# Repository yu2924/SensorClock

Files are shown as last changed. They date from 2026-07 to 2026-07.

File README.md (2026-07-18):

# SensorClock

🚧UNDER CONSTRUCTION🚧

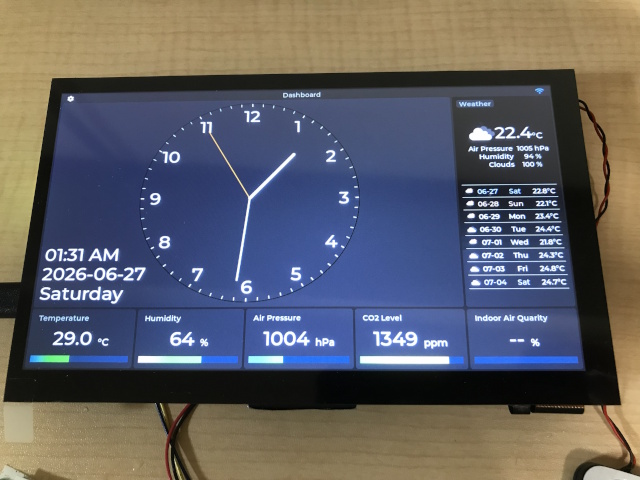
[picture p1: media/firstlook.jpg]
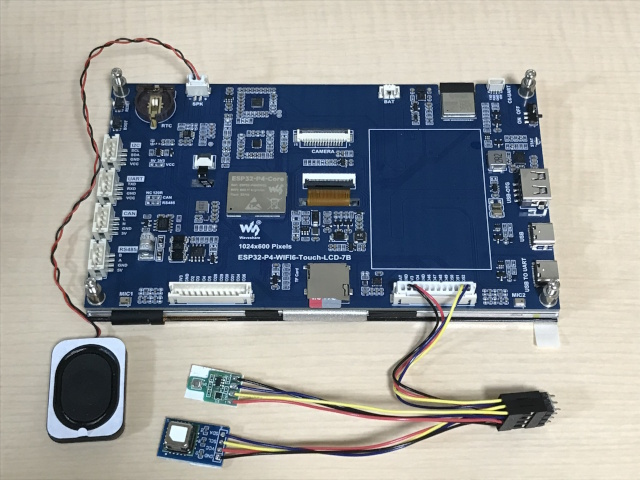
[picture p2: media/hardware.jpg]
 

> この家には壁掛け時計も置時計も無いな。一つ欲しいな。出来れば気温や湿度やCO2濃度なんかも見られたら良いな。

This is a documentation of my personal project to build a table clock with environmental sensors using a HMI display panel.

- It displays the current time and date, keeping the time synchronized using SNTP over Wi-Fi.
- It displays readings from environmental sensors, and optionally issues alerts when necessary.
- It displays a one-week weather forecast using [OpenWeather® One Call API 4.0](https://openweathermap.org/api/one-call-4). (API key required)
- It stores three months' worth of environmental data as a data logger and provides it in JSON format via an HTTP server.

**Table of Contents**

- [1. Hadrware](#1-hadrware)
	- [1.1. About Battery Operation](#11-about-battery-operation)
	- [1.2. 日本国内における技術基準適合証明](#12-日本国内における技術基準適合証明)
- [2. Tools Required for Development](#2-tools-required-for-development)
- [3. Firmware](#3-firmware)
	- [3.1. Introduction](#31-introduction)
	- [3.2. Configuration](#32-configuration)
	- [3.3. Preparing Fonts](#33-preparing-fonts)
	- [3.4. Options](#34-options)
		- [3.4.1. Choosing Screen Resolution](#341-choosing-screen-resolution)
		- [3.4.2. Enabling HTTPS Support for the HistoryServer](#342-enabling-https-support-for-the-historyserver)
	- [3.5. Security Consideration](#35-security-consideration)
	- [3.6. How The DataLogger and the HistoryServer Works](#36-how-the-datalogger-and-the-historyserver-works)
- [4. Developed by / License for the Created Data](#4-developed-by--license-for-the-created-data)
- [5. Acknowledgments](#5-acknowledgments)

## 1. Hadrware

- [WaveShare ESP32-P4-WIFI6-Touch-LCD-7B](https://docs.waveshare.com/ESP32-P4-WIFI6-Touch-LCD-7B) HMI display panel (7inch 1024 × 600)
- BME680 I2C temperature, humidity, barometric pressure, and gas sensor module
- SCD41 I2C CO2 sensor module



### 1.1. About Battery Operation

Since the steady-state current of the HMI panel is around 300 mA, battery power is not a practical option for a stationary device (IMO).

### 1.2. 日本国内における技術基準適合証明

この制作で使用したHMIディスプレイパネル製品は認証取得済みのモジュールを搭載しています。

- モジュール: ESP32-C6-MINI-1
- 認可番号: [007-AN0136](media/ESP32-C6-MINI-1%20TELEC%20Certification.pdf)

cf. [認証取得済みモジュールを内蔵する製品の場合](https://www.telec.or.jp/faq/#faq1_17)

---

## 2. Tools Required for Development

- [Visual Studio Code](https://code.visualstudio.com/)
- [ESP-IDF Extension for VS Code](https://marketplace.visualstudio.com/items?itemName=espressif.esp-idf-extension)
- [FontForge](https://fontforge.org/)
- [QCAD](https://www.qcad.org/)
- [OpenSCAD](https://openscad.org/)
- 3D printers
- solder and soldering irons
- wire strippers, wire cutters, pliers, files, screwdrivers, etc.

---

## 3. Firmware

### 3.1. Introduction

As I was getting started with firmware development, I learned that LVGL offers [a Win32 port](https://github.com/lvgl/lv_port_pc_visual_studio).  So, I decided to divide the application into modules, prototype most of the implementation to run on Windows, and replace only the platform-dependent modules with implementations using ESP-IDF/FreeRTOS functions.

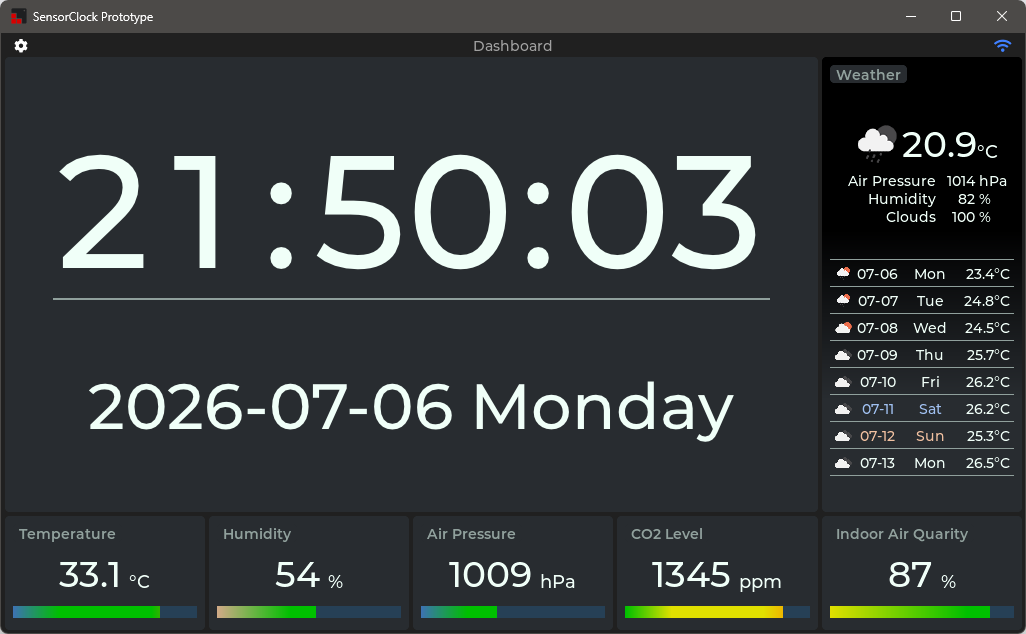
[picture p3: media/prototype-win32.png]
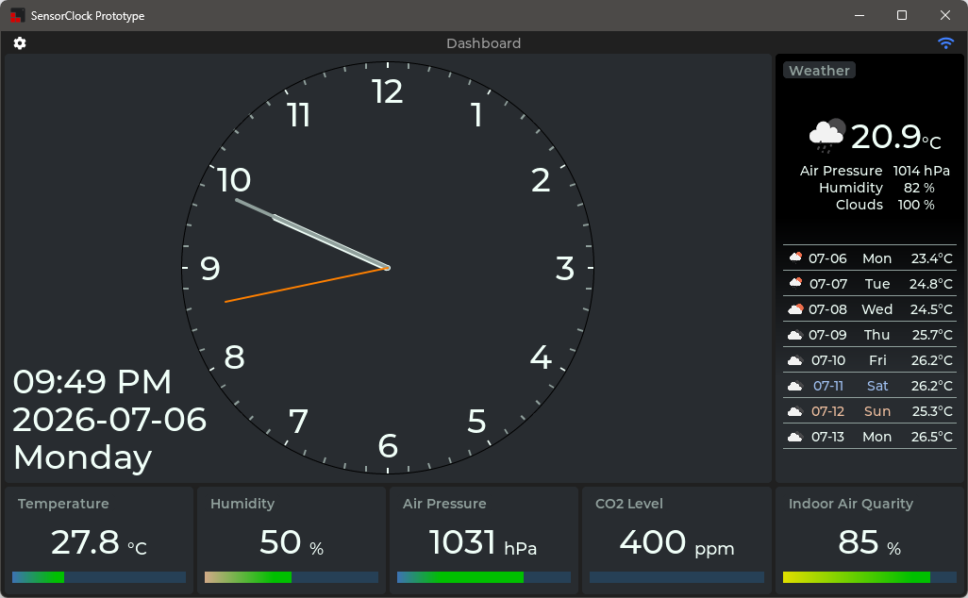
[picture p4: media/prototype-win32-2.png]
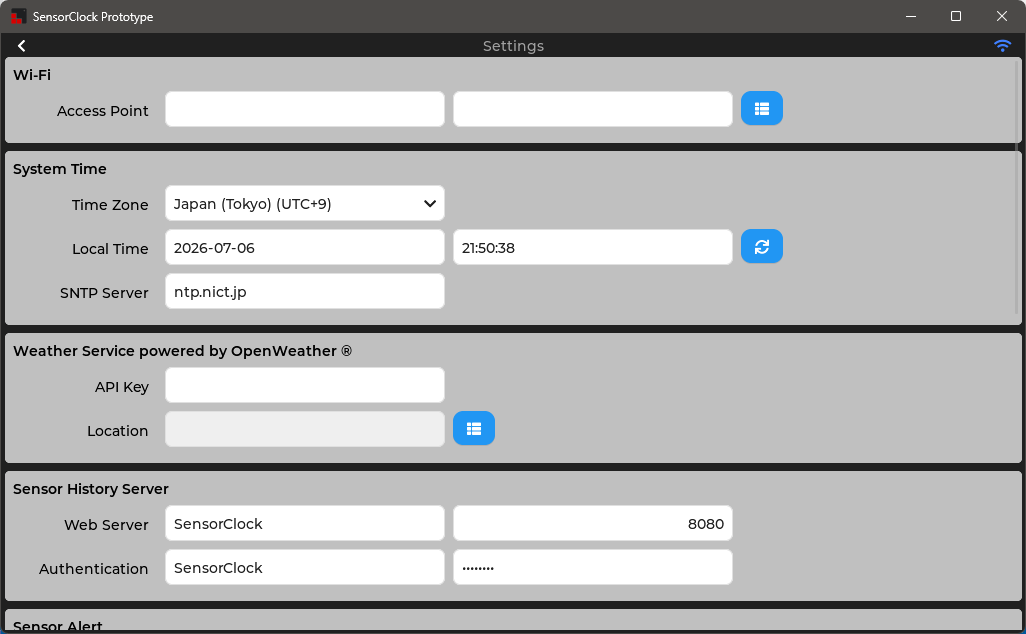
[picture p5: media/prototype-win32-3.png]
    
fig. prototype running on Windows

### 3.2. Configuration

**Platform**: This application used ESP-IDF v5.5.4 as the base framework and LVGL v9.5 for the GUI, along with the WaveShare's board support package (BSP).

**I2C port**: I found the drivers for the SCD4x and the BME680 on the Espressif Component Registry. These drivers are implemented using the i2cdev library; however, since the BSP and the i2cdev conflict during I2C initialization, so I decided to assign these sensors to a port other than the one assigned to the BSP.

**Assets**: Since rendering the clock requires a font with a larger point size, a TTF file itself is embedded as a asset. Also, several images, sounds, and texts are embedded too. So, I choosed the FrogFS to allow load these assets as read-only files.

Taking these factors into account, the following `sdkconfig` options are required:

- CONFIG_I2CDEV_DEFAULT_SDA_PIN=52
- CONFIG_I2CDEV_DEFAULT_SCL_PIN=51
- CONFIG_LV_USE_LODEPNG=y
- CONFIG_LV_USE_TINY_TTF=y
- CONFIG_LV_TINY_TTF_FILE_SUPPORT=y
- CONFIG_LV_GRADIENT_MAX_STOPS=4
- CONFIG_LV_FONT_MONTSERRAT_14=y
- CONFIG_LV_FONT_MONTSERRAT_18=y
- CONFIG_LV_FONT_MONTSERRAT_36=y
- CONFIG_LV_USE_LOG=y
- CONFIG_LV_FS_DEFAULT_DRIVER_LETTER=88 # 'X' : not required but recommended
- CONFIG_LV_USE_FS_FROGFS=y
- CONFIG_LV_FS_FROGFS_LETTER=87 # 'W'
- CONFIG_LV_BUILD_DEMOS=n
- CONFIG_LV_BUILD_EXAMPLES=n
- CONFIG_LV_USE_SYSMON=n

If the chip revision is less than 3, the following options are also required:

- CONFIG_ESP32P4_SELECTS_REV_LESS_V3=y

The command `esptool chip_id` can be used to check the actual chip version.

When encountering the linker error “Linker error: --enable-non-contiguous-regions discards section...”, the following option may be required:

- CONFIG_COMPILER_OPTIMIZATION_SIZE=y

The following options are effective for utilizing PSRAM and preserving limited internal memory:

- CONFIG_SPIRAM_ALLOW_BSS_SEG_EXTERNAL_MEMORY=y
- CONFIG_SPIRAM_ALLOW_NOINIT_SEG_EXTERNAL_MEMORY=y
- CONFIG_SPIRAM_RODATA=y
- CONFIG_SPIRAM_TRY_ALLOCATE_WIFI_LWIP=y
- CONFIG_SPIRAM_XIP_FROM_PSRAM=y

The following options are required but should be set by default:

- CONFIG_BSP_I2C_NUM=1
- CONFIG_BSP_I2S_NUM=1
- CONFIG_ESP_HTTP_CLIENT_ENABLE_HTTPS=y
- CONFIG_MBEDTLS_CERTIFICATE_BUNDLE=y

The “factory” partition is likely to overflow with the default partition table, so a custom partition table is required. 

To complete the configuration of the ESP-IDF project, it is sufficient to follow the steps below within the IDE:

1. Select "ESP-IDF v5.5.4"
2. Select "esp32-p4" → "ESP32-P4 chip (via builtin USB-JTAG)"

### 3.3. Preparing Fonts

In addition to the standard LVGL fonts, I have provided versions of main fonts with character sets expanded to be equivalent to Latin-1. I have also provided semi-bold styles. To do this, I used the online font converter.

[LVGL Font Converter](https://lvgl.io/tools/fontconverter)

```
(Here, XX represents the font size)
Name: lv_font_montserrat_latin1x_XX
Size: XX
Bpp: 4bit-per-pixel
Fallback: none
Output format: C file

TTF/WOFF font: Montserrat-Medium.ttf
Range: 0x20-0xFF,0x2022

TTF/WOFF font: TTF/WOFF font: FontAwesome5-Solid+Brands+Regular.woff
Range: 61441,61448,61451,61452,61452,61453,61457,61459,61461,61465,61468,61473,61478,61479,61480,61502,61507,61512,61515,61516,61517,61521,61522,61523,61524,61543,61544,61550,61552,61553,61556,61559,61560,61561,61563,61587,61589,61636,61637,61639,61641,61664,61671,61674,61683,61724,61732,61787,61931,62016,62017,62018,62019,62020,62087,62099,62212,62189,62810,63426,63650
```

These conversion parameters basically follow the LVGL script. The script is located in the LVGL folder `managed_components/lvgl__lvgl/scripts/built_in_font`, which is fetched after the project is configured.

I have also added the `Monserrat-Medium.ttf` file itself to the assets so that the font can be displayed in a larger point size. To reduce the final image size, I cut down the character set of the font to the equivalent of Latin-1.

### 3.4. Options

While using `Kconfig.projbuild` makes it easy to switch between IDF configurations, it cannot be used for prototype code on Windows. Therefore, I used a more primitive manual method.

#### 3.4.1. Choosing Screen Resolution

If using a different HMI display panel, the screen resolution can be selected.

- Edit `main/gui/GuiConfig.h` to enable the correct preprocessor macro:
  - SCREENRES_1024x600
  - SCREENRES_800x600
- Edit `main/CMakeLists.txt` to ensure the appropriate fonts are compiled:
  - `lv_font_montserrat_latin1x_14.c` and `lv_font_montserrat_semibold_latin1x_14.c` for 1024x600
  - `lv_font_montserrat_latin1x_12.c` and `lv_font_montserrat_semibold_latin1x_12.c` for 800x480
- Open the IDF configration menu and ensure that the required fonts are checked:
  - CONFIG_LV_FONT_MONTSERRAT_XX, here XX={ 14, 18, 32 } for 1024x600
  - CONFIG_LV_FONT_MONTSERRAT_XX, here XX={ 12, 14, 28 } for 800x480

#### 3.4.2. Enabling HTTPS Support for the HistoryServer

Although it is not mandatory, enabling HTTPS is also an option. Thanks to the ESP-IDF, no additional implementation is required to add HTTPS support, but it's a little troublesome to obtain valid server certificates.

- Locate server certificates at `main/certs`:
  - `prvtkey.pem`
  - `servercert.pem`
- Edit `main/CMakeLists.txt` to enable the embedding line:
  - EMBED_TXTFILES "certs/servercert.pem" "certs/prvtkey.pem"
- Edit `main/modules/HttpServerCore.config.h` to enable the preprocessor macro:
  - HTTPSERVER_SUPPORT_HTTPS

### 3.5. Security Consideration

Since I intend to use this project only for personal use at home, I’m not too concerned about security; however, if it were to be released as a product, at least NVS encryption would be desirable. The Wi-Fi accespoint/passphrase and the API key are stored there.

### 3.6. How The DataLogger and the HistoryServer Works

The DataLogger collects a history of measurements from environmental sensors and weather data.

- It records the measurements from the sensors every 10 minutes, and the weather data is recorded every hour.
- It stores three months' worth of data in the internal volatile RAM.
- A micro SD card can be used for persistence (optional). The estimated amount of data written to the SD card is approximately 30MB/day, or 11GB/year. This amount of writing is excessive for the internal flash partition.
- All measured values are in metric units, i.e., °C, hPa, ppm, meters/second, etc.

The HistoryServer provides data collected by the DataLogger in JSON format via a web interface.

- Thanks to the mDNS server, it can be accessed by its server name.
- Allows clients to specify a time range for queries.

Example of request (HTTP/1.1 GET):
```
http://sensorclock.local/sensor?from=1777474800&to=1777561200
http://sensorclock.local/weather?from=1777474800&to=1777561200
```
- from: The UNIX timestamp at the start of the time range (optional)
- to: The UNIX timestamp at the end of the time range (optional)

Example of response:
```
{
	"status": "200 OK",
	"path": "/sensor",
	"from": "1777474800",
	"to": "1777561200",
	"length": "8",
	"data": [
		{
			"dt": "1777555800",
			"temp": "25.9",
			"humidity": "44",
			"pressure": "1013",
			"co2": "691",
			"iaq": "98"
		},
	...
	]
}
```
```
{
	"status": "200 OK",
	"path": "/weather",
	"from": "1777474800",
	"to": "1777561200",
	"length": "8",
	"data": [
		{
			"dt": "1777528800",
			"temp": "23.2",
			"pressure": "1006",
			"humidity": "36",
			"cloud": "69",
			"wind_speed": "0.45",
			"wind_deg": "329",
			"weather_id": "803",
			"weather_icon": "04n"
		},
	...
	]
}
```

---

## 4. Developed by / License for the Created Data

The CAD data for the enclosure and the source code for the firmware are developed by [yu2924](https://x.com/yu2924/) and released under CC0 1.0 Universal.

## 5. Acknowledgments

- [raspi-bme680-iaq by thstielow](https://github.com/thstielow/raspi-bme680-iaq)  Thanks for the great implementation.
- [svgSimpleImages by aikige](https://github.com/aikige/svgSimpleImages)  Thanks for the helpful images.

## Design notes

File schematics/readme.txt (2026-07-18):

SCD41 module
details unknown; purchased from AliExpress

BME680 module
https://akizukidenshi.com/catalog/g/g114469/

If the sensor modules have pull-ups, no additional pull-ups are required.

I used a QI (2550) connector for the I2C, but the pin layout and colors followed the Qwiic standard.

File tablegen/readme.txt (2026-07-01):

This folder contains the tools for generating JSON tables from TSV files.
Once generated, the JSON tables should be copied to the "firmware/assets" folder for use.
Currently, it is used to generate the following tables:
- list of representative time zones
- list of 3rd party license notices

Usage:

python tsv_to_json.py timezones50.tsv
python tsv_to_json.py table_of_licenses.tsv

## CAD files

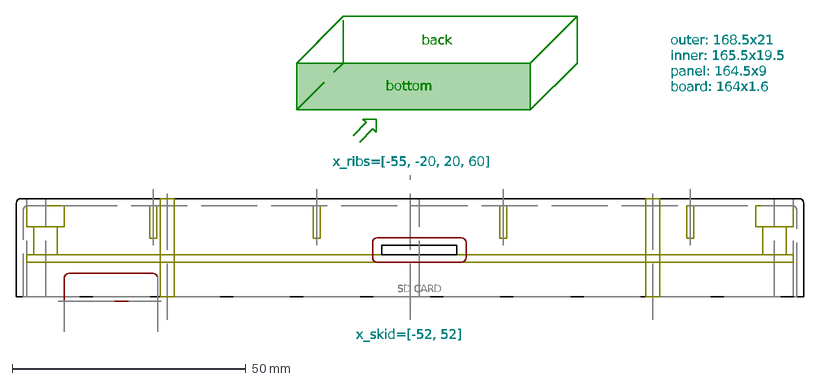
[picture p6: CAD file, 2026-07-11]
enclosure/face-bottom.dxf
SD CARD
back
bottom
x_ribs=[-55, -20, 20, 60]
outer: 168.5x21 inner: 165.5x19.5 panel: 164.5x9 board: 164x1.6
x_skid=[-52, 52]

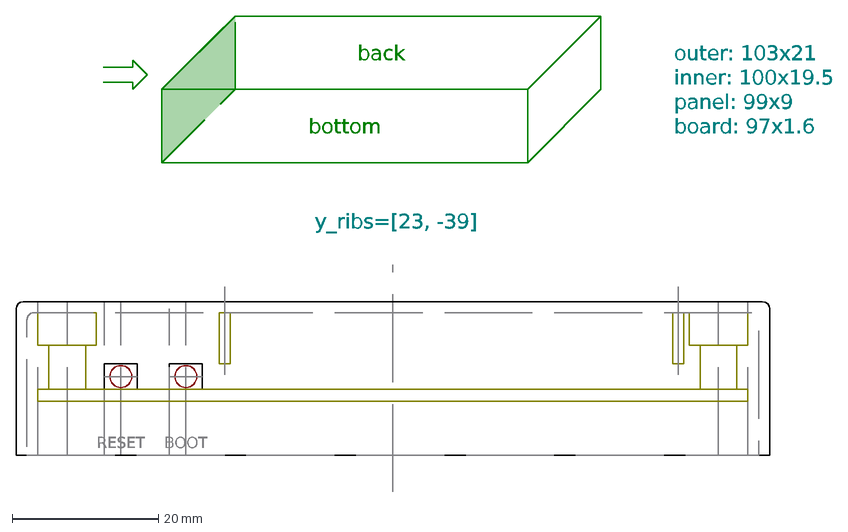
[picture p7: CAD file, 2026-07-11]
enclosure/face-left.dxf
RESET
BOOT
back
bottom
y_ribs=[23, -39]
outer: 103x21 inner: 100x19.5 panel: 99x9 board: 97x1.6

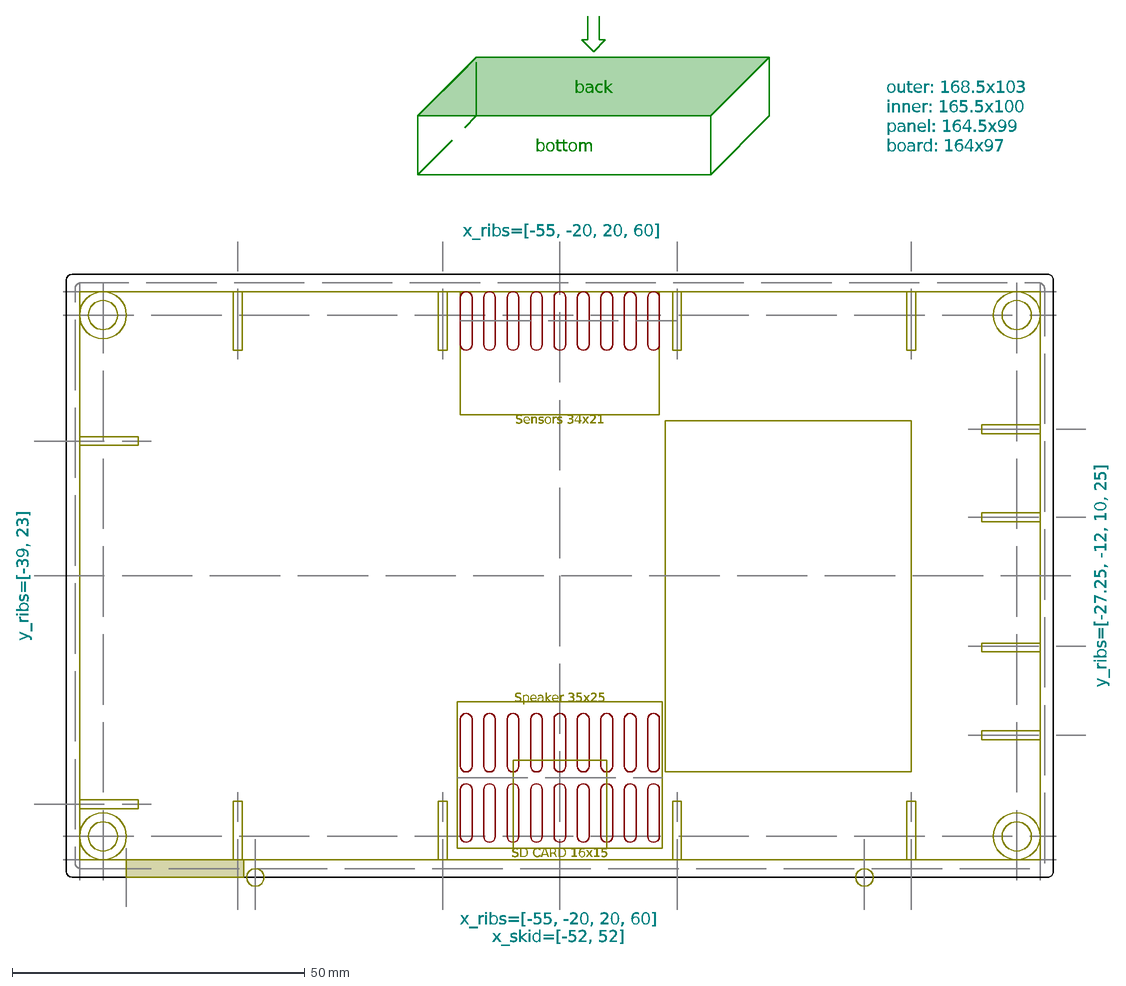
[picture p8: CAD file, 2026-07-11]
enclosure/face-back.dxf
back
bottom
x_ribs=[-55, -20, 20, 60]
y_ribs=[-39, 23]
y_ribs=[-27.25, -12, 10, 25]
Sensors 34x21
Speaker 35x25
SD CARD 16x15
outer: 168.5x103 inner: 165.5x100 panel: 164.5x99 board: 164x97
x_skid=[-52, 52]

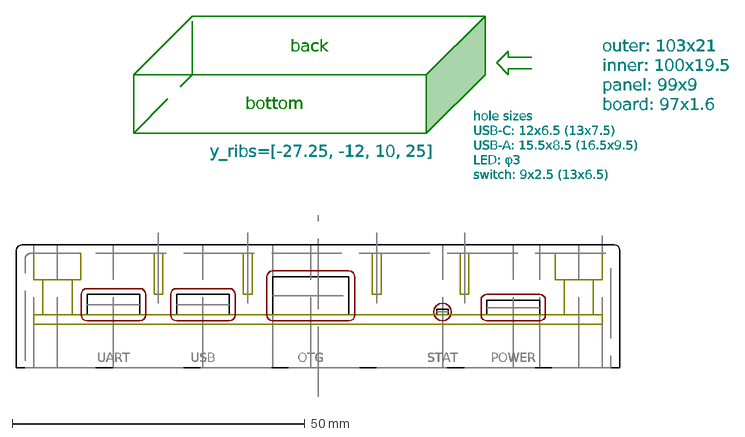
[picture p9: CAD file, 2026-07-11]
enclosure/face-right.dxf
UART
USB
OTG
STAT
POWER
back
bottom
hole sizes USB-C: 12x6.5 (13x7.5) USB-A: 15.5x8.5 (16.5x9.5) LED: φ3 switch: 9x2.5 (13x6.5)
y_ribs=[-27.25, -12, 10, 25]
outer: 103x21 inner: 100x19.5 panel: 99x9 board: 97x1.6

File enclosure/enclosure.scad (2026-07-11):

//
//  enclosure.scad
//  SensorClock
//
//  created by yu2924 on 2026-05-04
//

include <BOSL/constants.scad>
use <BOSL/shapes.scad>

$fn=30;

// terminology
// x: width
// y: height
// z: depth

Epsilon         = 0.01;

ShellThickness  = 1.5;
BoardWidth      = 164;
BoardHeight     = 97;
PanelWidth      = 164.5;
PanelHeight     = 99;
PanelDepth      = 9;
MountPostDepth  = 6;
PartsDepth      = 10.5;
PanelMargin     = 0.5;
Fillet          = 1.5;

EnclosureWidth      = PanelWidth  + (ShellThickness + PanelMargin) * 2; // 168.5
EnclosureHeight     = PanelHeight + (ShellThickness + PanelMargin) * 2; // 103
EnclosureDepth      = PanelDepth + PartsDepth + ShellThickness; // 21
echo("EncrosureWidth=", EnclosureWidth);
echo("EnclosureHeight=", EnclosureHeight);
echo("EnclosureDepth=", EnclosureDepth);

// --------------------------------------------------------------------------------
// box shell

module boxshell()
{
    w = EnclosureWidth;
    h = EnclosureHeight;
    d = EnclosureDepth;
    th = ShellThickness;
    f = Fillet;
    // cut in half
    difference()
    {
        // rounded hollow shell
        difference()
        {
            cuboid([w, h, d * 2], fillet=f);
            cuboid([w - th * 2, h - th * 2, d * 2 - th * 2], fillet = f - 1);
        }
        downcube([w + 0.1, h + 0.1, d + 0.1]);
    }
}

// --------------------------------------------------------------------------------
// punch holes

module rightholes()
{
    translate([EnclosureWidth/2, -EnclosureHeight/2, 0])
      rotate([0, 0, 90])
        rotate([90, 0, 0])
          translate([0, 0, -ShellThickness * 3])
            linear_extrude(height = ShellThickness * 4, center = false, convexity = 10)
              import(file = "face-right.dxf", layer = "holes");
}

module leftholes()
{
    translate([-EnclosureWidth / 2, EnclosureHeight / 2, 0])
      rotate([0, 0, -90])
        rotate([90, 0, 0])
          translate([0, 0, -ShellThickness * 3])
            linear_extrude(height = ShellThickness * 4, center = false, convexity = 10)
              import(file = "face-left.dxf", layer = "holes");
}

module bottomholes()
{
    translate([-EnclosureWidth / 2, -EnclosureHeight / 2, 0])
      rotate([90, 0, 0])
        translate([0, 0, -ShellThickness * 3])
          linear_extrude(height = ShellThickness * 4, center = false, convexity = 10)
            import(file = "face-bottom.dxf", layer = "holes");
}

module backholes()
{
    translate([-EnclosureWidth / 2, -EnclosureHeight / 2, EnclosureDepth])
      translate([0, 0, -ShellThickness * 3])
        linear_extrude(height = ShellThickness * 4, center = false, convexity = 10)
          import(file = "face-back.dxf", layer = "holes");
}

module allholes()
{
    leftholes();
    rightholes();
    bottomholes();
    backholes();
}

// --------------------------------------------------------------------------------
// mounting posts

module mountingboss(x, y)
{
    dpost = EnclosureDepth - PanelDepth - MountPostDepth - ShellThickness + Epsilon;
    echo("MountingPostDepth=", dpost);
    diapost = 8;
    lrib = 4; // x|y length of ribs
    thrib = 1.5; // thickness of ribs
    translate([x, y, PanelDepth + MountPostDepth])
    {
      tube(dpost, od=diapost, id=3);
      translate([diapost / 2, 0, 0])
        upcube([lrib, thrib, dpost]);
      translate([-diapost / 2, 0, 0])
        upcube([lrib, thrib, dpost]);
      translate([0, diapost / 2, 0])
        upcube([thrib, lrib, dpost]);
      translate([0, -diapost / 2, 0])
        upcube([thrib, lrib, dpost]);
    }
}

module allmoutingbosses()
{
    ScrewHoleOffset = 4;
    x = BoardWidth / 2 - ScrewHoleOffset;
    y = BoardHeight / 2 - ScrewHoleOffset;
    mountingboss(-x,  y);
    mountingboss( x,  y);
    mountingboss( x, -y);
    mountingboss(-x, -y);
}

module counterbore(x, y)
{
    screwheaddepth = 2;
    screwheaddia = 5;
    translate([x, y, EnclosureDepth])
      cyl(d=screwheaddia, h=screwheaddepth * 2);
}

module allcounterbore()
{
    ScrewHoleOffset = 4;
    x = BoardWidth / 2 - ScrewHoleOffset;
    y = BoardHeight / 2 - ScrewHoleOffset;
    counterbore(-x,  y);
    counterbore( x,  y);
    counterbore( x, -y);
    counterbore(-x, -y);
}

// --------------------------------------------------------------------------------
// ribs

module rib(x, y, angle)
{
    // NOTE: angle=0 means along the x-axis, increase in the ccw direction
    lrib = 10; // x|y length
    drib = 7; // z depth
    thrib = 1.5; // thickness
    translate([x, y, EnclosureDepth - drib - ShellThickness + Epsilon])
      rotate([0, 0, angle])
        cuboid([lrib, thrib, drib], fillet=3, edges=EDGE_BOT_RT, align=[1,0,1]);
}

module allribs()
{
    // top
    ytop = EnclosureHeight / 2 - ShellThickness + Epsilon;
    for(x = [-55,-20,20,60])
    {
        rib(x, ytop, -90);
    }
    // bottom
    ybottom = -EnclosureHeight / 2 + ShellThickness - Epsilon;
    for(x = [-55,-20,20,60])
    {
        rib(x, ybottom, 90);
    }
    // left
    xl = -EnclosureWidth / 2 + ShellThickness - Epsilon;
    for(y = [-39,23])
    {
        rib(xl, y, 0);
    }
    // right
    xr = EnclosureWidth / 2 - ShellThickness + Epsilon;
    for(y = [-27.25,-12,10,25])
    {
        rib(xr, y, 180);
    }
}

// --------------------------------------------------------------------------------
// skids

module skid(x)
{
    translate([x, -EnclosureHeight / 2, EnclosureDepth / 2])
      cyl(l=EnclosureDepth, r=1.5);
}

module allskids()
{
    skid(-52);
    skid( 52);
}

// --------------------------------------------------------------------------------
// assembly

difference()
{
    union()
    {
        boxshell();
        allmoutingbosses();
        allribs();
        allskids();
    }
    union()
    {
        allholes();
        allcounterbore();
    }
}

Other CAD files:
enclosure/enclosure.stl

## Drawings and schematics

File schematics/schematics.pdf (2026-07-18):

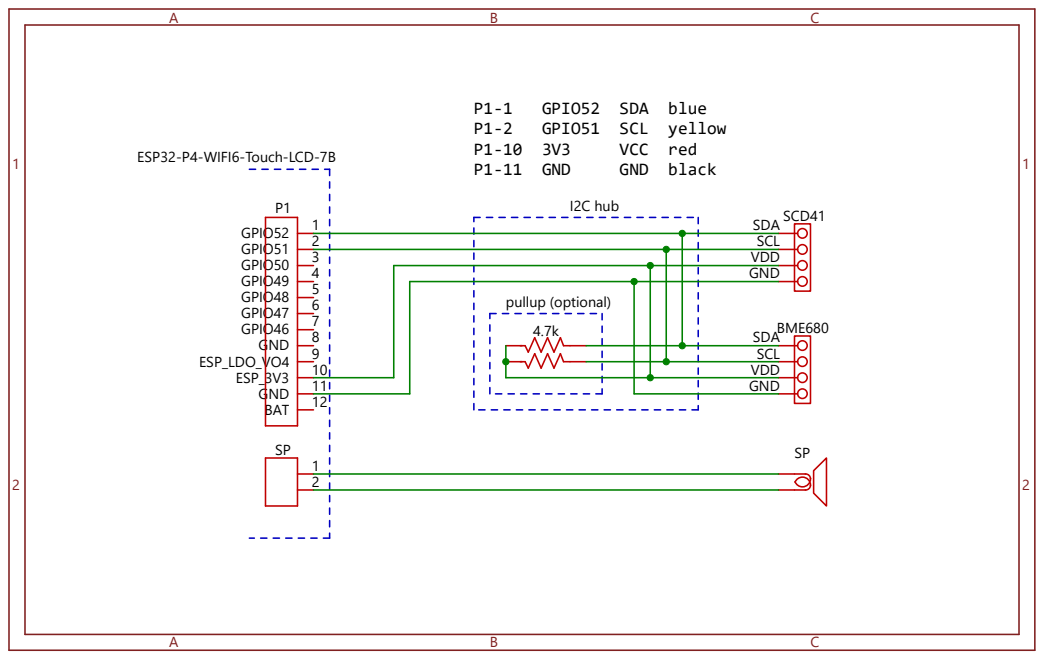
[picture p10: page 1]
GPIO52 SDA blue; GPIO51 SCL yellow; VCC red; P1-11 GND; GND black; I2C hub; pullup (optional); ESP32-P4-WIFI6-Touch-LCD-7B; GPIO52; GPIO51; GPIO50; GPIO49; GPIO48; GPIO47; GPIO46; GND; ESP_LDO_VO4; ESP_3V3; BAT; SDA SCL VDD GND; SCD41; BME680

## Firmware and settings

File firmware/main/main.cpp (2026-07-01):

//
//  main.cpp
//  SensorClock
//
//  created by yu2924 on 2025-11-16
//

#if defined(_WINDOWS)

// ================================================================================
// Prototype code for Windows

#define STRICT
#if !defined NOMINMAX
#define NOMINMAX
#endif
#include <Windows.h>
#include <crtdbg.h>
#include <LvglWindowsIconResource.h>
#include <lvgl.h>
#include "modules/AppController.h"
#include "modules/Dispatcher.h"
#include "gui/GuiInit.h"

struct ScopedCoinitialize
{
	ScopedCoinitialize() { if(FAILED(CoInitializeEx(NULL, COINIT_MULTITHREADED))) { OutputDebugStringW(L"CoInitializeEx() failed\n"); } }
	~ScopedCoinitialize() { CoUninitialize(); }
};

struct ScopedWsaInit
{
	ScopedWsaInit() { WSADATA wsaData; if(WSAStartup(MAKEWORD(2, 2), &wsaData) != 0) { OutputDebugStringW(L"WSAStartup() failed\n"); } }
	~ScopedWsaInit() { WSACleanup(); }
};

static void lvLogPrintCb(lv_log_level_t level, const char* buf)
{
	char s[1024]; snprintf(s, std::size(s), "%s\n", buf);
	OutputDebugStringA(s);
}

struct AppContainer
{
	xheap::uniquePtr<AppController> appController = AppController::createInstance();
	xheap::uniquePtr<gui::GuiInit> guiInit = gui::GuiInit::createInstance(appController.get());
	AppContainer()
	{
	}
	void startup()
	{
		guiInit->create();
		appController->activate();
	}
};

xheap::uniquePtr<AppContainer> gAppContainer;

static void __cdecl OnExitProc()
{
	OutputDebugStringW(L"OnExitProc\n");
	if(gAppContainer) gAppContainer.reset();
}

int WINAPI wWinMain(_In_ HINSTANCE hInstance, _In_opt_ HINSTANCE, _In_ LPWSTR, _In_ int)
{
	ScopedCoinitialize coinit;
	ScopedWsaInit wsaInit;
	_CrtSetDbgFlag(_CRTDBG_ALLOC_MEM_DF | _CRTDBG_LEAK_CHECK_DF);
	_CrtSetReportMode(_CRT_WARN, _CRTDBG_MODE_DEBUG);
	lv_init();
	lv_log_register_print_cb(lvLogPrintCb);
	lv_display_t* display = lv_windows_create_display(L"SensorClock Prototype", gui::getScreenWidth(), gui::getScreenHeight(), 100, false, false);
	if(!display) { return -1; }
	HWND hwnd = lv_windows_get_display_window_handle(display);
	if(!hwnd) { return -1; }
	lv_indev_t* pointer_indev = lv_windows_acquire_pointer_indev(display);
	if(!pointer_indev) { return -1; }
	lv_indev_t* keypad_indev = lv_windows_acquire_keypad_indev(display);
	if(!keypad_indev) { return -1; }
	lv_indev_t* encoder_indev = lv_windows_acquire_encoder_indev(display);
	if(!encoder_indev) { return -1; }
	if(HICON hicon = LoadIconW(hInstance, MAKEINTRESOURCE(IDI_LVGL_WINDOWS)))
	{
		SendMessageW(hwnd, WM_SETICON, TRUE, (LPARAM)hicon);
		SendMessageW(hwnd, WM_SETICON, FALSE, (LPARAM)hicon);
	}
	atexit(OnExitProc);
	Dispatcher* disp = Dispatcher::getMainDispatcher();
	gAppContainer = xheap::makeUnique<AppContainer>();
	gAppContainer->startup();
	disp->runEventLoop();
	return 0;
}

#elif defined(ESP_PLATFORM)

// ================================================================================
// Production code for ESP32

#include <esp_err.h>
#include <esp_event.h>
#include <esp_log.h>
#include <esp_wifi.h>
#include <i2cdev.h>
#include <nvs.h>
#include <nvs_flash.h>
#include <lvgl.h>

#include <bsp/display.h>
#include <bsp/esp-bsp.h>

#include "utilities/cjsonwrap.h"
#include "utilities/platform.h"
#include "modules/AppController.h"
#include "modules/Dispatcher.h"
#include "gui/GuiInit.h"

static const char* TagApp = "App";
/*
struct ScopedDisplayLock
{
	ScopedDisplayLock(uint32_t t = -1) { bsp_display_lock(t); }
	~ScopedDisplayLock() { bsp_display_unlock(); }
};
*/

static void lvLogPrintCb(lv_log_level_t lvlev, const char* buf)
{
	static const char* TagLvga = "LVGA";
	int esplev = ESP_LOG_NONE;
	char levchr = 'I';
	switch(lvlev)
	{
		case LV_LOG_LEVEL_TRACE	: esplev = ESP_LOG_VERBOSE	; levchr = 'V'; break;
		case LV_LOG_LEVEL_INFO	: esplev = ESP_LOG_INFO		; levchr = 'I'; break;
		case LV_LOG_LEVEL_WARN	: esplev = ESP_LOG_WARN		; levchr = 'W'; break;
		case LV_LOG_LEVEL_ERROR	: esplev = ESP_LOG_ERROR	; levchr = 'E'; break;
		case LV_LOG_LEVEL_USER	: esplev = ESP_LOG_DEBUG	; levchr = 'D'; break;
	}
	esp_log(ESP_LOG_CONFIG_INIT(esplev), TagLvga, "%c (%ld) %s: ", levchr, esp_log_timestamp(), TagLvga);
	printf("%s\n", buf);
}

void debugPrintHeapStat()
{
	static const struct { uint32_t cap; const char* label; } Table[] =
	{
		{ MALLOC_CAP_SPIRAM		, "spi" },
		{ MALLOC_CAP_INTERNAL	, "int" },
		{ MALLOC_CAP_DMA		, "dma" },
		{ MALLOC_CAP_DEFAULT	, "def" },
	};
	printf("%-6s %8s %8s %8s\n", "caps", "allfree", "largest", "total");
	for(const auto& ent : Table)
	{
		size_t allfree = heap_caps_get_free_size(ent.cap);
		size_t largest = heap_caps_get_largest_free_block(ent.cap);
		size_t total   = heap_caps_get_total_size(ent.cap);
		printf("%-6s %8u %8u %8u\n", ent.label, allfree, largest, total);
	}
}

// custom allocator using PSRAM for LVGL
// cf. https://github.com/lvgl/lvgl/issues/8191
extern "C"
{
	void lv_mem_init(void) {}
	void lv_mem_deinit(void) {}
	lv_mem_pool_t lv_mem_add_pool(void*, size_t) { return NULL; }
	void lv_mem_remove_pool(lv_mem_pool_t) {}
	void* lv_malloc_core(size_t size) { return heap_caps_malloc(size, MALLOC_CAP_SPIRAM); }
	void* lv_realloc_core(void* p, size_t new_size) { return heap_caps_realloc(p, new_size, MALLOC_CAP_SPIRAM); }
	void lv_free_core(void* p) { heap_caps_free(p); }
	void lv_mem_monitor_core(lv_mem_monitor_t*) {}
	lv_result_t lv_mem_test_core(void) { return LV_RESULT_OK; }
}

// --------------------------------------------------------------------------------

struct AppContainer
{
	xheap::uniquePtr<AppController> appController;
	xheap::uniquePtr<gui::GuiInit> guiInit;
	void startup()
	{
		ESP_LOGI(TagApp, "AppContainer startup begin");
		appController = AppController::createInstance();
		ESP_LOGI(TagApp, "AppController construction done");
		guiInit = gui::GuiInit::createInstance(appController.get());
		guiInit->create();
		bsp_display_backlight_on();
		ESP_LOGI(TagApp, "gui creation done");
		appController->activate();
		ESP_LOGI(TagApp, "AppController activation done");
		debugPrintHeapStat();
		ESP_LOGI(TagApp, "AppContainer startup end");
	}
};

xheap::uniquePtr<AppContainer> gAppContainer;

extern "C" void app_main(void)
{
	// bsp
	// NOTE: bsp_display_start_with_config() includes the following steps:
	//   setup both the lcd and the touch devices
	//   call lvgl_port_init() that create the its own LVGL task, call lv_init() within the task
	bsp_display_cfg_t cfg =
	{
		.lvgl_port_cfg = ESP_LVGL_PORT_INIT_CONFIG(),
		.buffer_size = BSP_LCD_DRAW_BUFF_SIZE,
		.double_buffer = BSP_LCD_DRAW_BUFF_DOUBLE,
		.flags =
		{
			.buff_dma = true,
			.buff_spiram = true,
			.sw_rotate = true,
		}
	};
	if(lv_display_t* display = bsp_display_start_with_config(&cfg))
	{
		// bsp_display_backlight_on();
		bsp_display_rotate(display, LV_DISPLAY_ROTATION_180);
	}
	// ----------------------------------------
	// idf
	esp_err_t r = nvs_flash_init();
	if((r == ESP_ERR_NVS_NO_FREE_PAGES) || (r == ESP_ERR_NVS_NEW_VERSION_FOUND))
	{
		ESP_ERROR_CHECK(nvs_flash_erase());
		r = nvs_flash_init();
	}
	ESP_ERROR_CHECK(r);
	ESP_ERROR_CHECK(esp_event_loop_create_default());
	// ----------------------------------------
	// app
	lv_log_register_print_cb(lvLogPrintCb);
	cjsonwrap::initWithHeapAllocators();
	WifiConnection::platformInit();
	SensorTask::platformInit();
	AlarmSounder::platformInit();
	Dispatcher* disp = Dispatcher::getMainDispatcher();
	gAppContainer = xheap::makeUnique<AppContainer>();
	gAppContainer->startup();
	disp->runEventLoop();
}

#else
#error unknown platform
#endif // defined(_WINDOWS) / defined(ESP_PLATFORM)

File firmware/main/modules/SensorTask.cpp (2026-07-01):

//
//  SensorTask.cpp
//  SensorClock
//
//  created by yu2924 on 2025-12-20
//

#include "SensorTask.h"

#include <cmath>

const std::array<SensorTask::Metadata, SensorTask::Icount> SensorTask::MetadataList =
{
	Metadata{ "CO2 Level"			, "ppm"			, "sco2", false },
	Metadata{ "Temperature"			, "\xc2\xb0""C"	, "stmp", false },
	Metadata{ "Humidity"			, "%"			, "shum", true  },
	Metadata{ "Temperature"			, "\xc2\xb0""C"	, "btmp", false },
	Metadata{ "Air Pressure"		, "hPa"			, "bprs", false },
	Metadata{ "Humidity"			, "%"			, "bhum", true },
	Metadata{ "Indoor Air Quarity"	, "%"			, "biaq", true }
};

const SensorTask::Thresholds SensorTask::Thresholds::Ranges
{
	{
		{ 400, 2000 }, // scd4x co2
		{ -10,   60 }, // scd4x temp
		{   0,  100 }, // scd4x hum
		{ -40,   85 }, // bme680 temp
		{ 300, 1100 }, // bme680 pres
		{   0,  100 }, // bme680 hum
		{   0,  100 }, // bme680 iaq
	},
	0
};

const SensorTask::Thresholds SensorTask::Thresholds::Defaults
{
	{
		{ 400, 1500 }, // scd4x co2
		{  25,   35 }, // scd4x temp
		{  40,   60 }, // scd4x hum
		{  25,   35 }, // bme680 temp
		{  980, 1050 }, // bme680 pres
		{  40,   60 }, // bme680 hum
		{  75,  100 }, // bme680 iaq
	},
	0
};

SensorTask::Falerts SensorTask::calculateAlertFlags(const Thresholds& th, const Values& val)
{
	Falerts falerts = 0;
	for(int i = 0; i < Icount; ++i)
	{
		const auto& rng = th.array[i];
		float v = val[i];
		Falerts ma = 1 << i;
		if((th.alerts & ma) && !std::isnan(v) && ((v < rng.under) || (rng.over < v))) falerts |= ma;
	}
	return falerts;
}

#if defined(_WINDOWS)

// ================================================================================
// Prototype code for Windows
// It simply outputs dummy data.

#include <random>
#include "utilities/listenerlist.h"
#include "modules/Dispatcher.h"

class SensorTaskImpl : public SensorTask, private DispatchTimer::Listener
{
public:
	xheap::uniquePtr<DispatchTimer> timer = DispatchTimer::createInstance();
	ListenerListT<SensorTask::Listener> listenerList;
	Thresholds thresholds = Thresholds::Defaults;
	Values values{};
	Falerts alertFlags = 0;
	SensorTaskImpl()
	{
		timer->addListener(this);
	}
	~SensorTaskImpl() override
	{
		timer->removeListener(this);
	}
	void addListener(SensorTask::Listener* p) override
	{
		listenerList.add(p);
	}
	void removeListener(SensorTask::Listener* p) override
	{
		listenerList.remove(p);
	}
	const Thresholds& getThresholds() const override
	{
		return thresholds;
	}
	void setThresholds(const Thresholds& v) override
	{
		if(thresholds == v) { return; }
		thresholds = v;
		alertFlags = calculateAlertFlags(thresholds, values);
		listenerList.call(&SensorTask::Listener::sensorTaskThresholdsDidChange, this, thresholds);
	}
	bool isActive() const override
	{
		return timer->isRunning();
	}
	bool activate() override
	{
		dispatchTimerDidElapse(timer.get());
		timer->start(5000);
		srand(0);
		return true;
	}
	void deactivate() override
	{
		timer->stop();
	}
	const Values& getValues() const override
	{
		return values;
	}
	Falerts getAlertFlags() const override
	{
		return alertFlags;
	}
	// DispatchTimer::Listener
	void dispatchTimerDidElapse(DispatchTimer*) override
	{
		// dummy data
		static std::random_device seed_gen;
		static std::uint32_t seed = seed_gen();
		static std::mt19937 engine(seed);
		static std::uniform_real_distribution<float> dist(-1, 1);
		values = {};
		for(int isensor = 0; isensor < Icount; ++isensor)
		{
			const auto& rng = Thresholds::Ranges.array[isensor];
			const auto& th = thresholds.array[isensor];
			float center = (th.over + th.under) * 0.5f;
			float amp = (th.over - th.under) * 0.5f * 1.5f;
			float v = center + amp * dist(engine);
			values[isensor] = std::max(rng.under, std::min(rng.over, v));
		}
		alertFlags = calculateAlertFlags(thresholds, values);
		const Fupdates fupdates = Fscd4xAll | Fbme680All;
		listenerList.call(&SensorTask::Listener::sensorTaskValuesDidChange, this, fupdates, values);
	}
};

void SensorTask::platformInit()
{
}

xheap::uniquePtr<SensorTask> SensorTask::createInstance()
{
	return xheap::makeUnique<SensorTask, SensorTaskImpl>();
}

#elif defined(ESP_PLATFORM)

// ================================================================================
// Production code for ESP32

#include <freertos/FreeRTOS.h>
#include <freertos/task.h>
#include <esp_log.h>
#include <esp_task.h>
#include <bme680.h>
#include <scd4x.h>
#include "utilities/listenerlist.h"
#include "modules/bme6801IAQ_esp32.h"
#include "modules/Dispatcher.h"

static constexpr i2c_port_t SENSORTASK_I2CPORT = I2C_NUM_0;
static constexpr gpio_num_t SENSORTASK_SDAPIN = (gpio_num_t)CONFIG_I2CDEV_DEFAULT_SDA_PIN;
static constexpr gpio_num_t SENSORTASK_SCLPIN = (gpio_num_t)CONFIG_I2CDEV_DEFAULT_SCL_PIN;

static const char* TagScd4x = "SCD4x";

struct Scd4xHandler
{
	static constexpr uint8_t Scd4xHandler_I2C_ADDR = SCD4X_I2C_ADDR; // 0x62
	static constexpr int IntervalPeriodicMs = 5000;
	static constexpr int IntervalLowPowerPeriodicMs = 30000;
	i2c_dev_t dev{};
	TickType_t tkMeasureInterval = 0;
	TickType_t tkMeasureLast = 0;
	bool initialized = false;
	Scd4xHandler() = delete;
	Scd4xHandler(i2c_port_t port, gpio_num_t pinsda, gpio_num_t pinscl)
	{
		// scd4x default: dev.cfg.master.clk_speed = 100000;
		ESP_ERROR_CHECK_WITHOUT_ABORT(scd4x_init_desc(&dev, port, pinsda, pinscl));
	}
	~Scd4xHandler()
	{
		stop();
		scd4x_free_desc(&dev);
	}
	bool start(bool lowpower)
	{
		tkMeasureInterval = 0;
		tkMeasureLast = 0;
		initialized = false;
		esp_err_t r = scd4x_wake_up(&dev);
		if(r != ESP_OK) { ESP_LOGW(TagScd4x, "scd4x_wake_up() failed"); }
		r = scd4x_stop_periodic_measurement(&dev);
		if(r != ESP_OK) { ESP_LOGW(TagScd4x, "scd4x_stop_periodic_measurement() failed"); }
		r = scd4x_reinit(&dev);
		if(r != ESP_OK) { ESP_LOGW(TagScd4x, "scd4x_reinit() failed"); return false; }
		uint16_t sn[3]{};
		scd4x_get_serial_number(&dev, sn, sn + 1, sn + 2);
		ESP_LOGI(TagScd4x, "get_serial_number SN=0x%04x%04x%04x", sn[0], sn[1], sn[2]);
		if(lowpower) scd4x_start_low_power_periodic_measurement(&dev);
		else		 scd4x_start_periodic_measurement(&dev);
		int measintms = lowpower ? IntervalLowPowerPeriodicMs : IntervalPeriodicMs;
		tkMeasureInterval = pdMS_TO_TICKS(measintms);
		tkMeasureLast = xTaskGetTickCount();
		initialized = true;
		return true;
	}
	void stop()
	{
		if(!initialized) { return; }
		scd4x_stop_periodic_measurement(&dev);
		initialized = false;
	}
	bool tryRead(float* pco2, float* ptemp, float* phum)
	{
		if(!initialized) { return false; }
		TickType_t tkread = xTaskGetTickCount();
		if(tkread < tkMeasureLast + tkMeasureInterval) { return false; }
		uint16_t co2 = 0; float temp = 0, hum = 0;
		if(scd4x_read_measurement(&dev, &co2, &temp, &hum) != ESP_OK) { return false; }
		tkMeasureLast = tkread;
		// ESP_LOGI(TagScd4x, "read_measurement co2=%u temp=%.1f hum=%.0f", (uint32_t)co2, temp, hum);
		if(pco2) { *pco2 = (float)co2; }
		if(ptemp) { *ptemp = temp; }
		if(phum) { *phum = hum; }
		return true;
	}
};
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

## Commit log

2026-07-01 Initial commit
    wip
    [enclosure.scad, enclosure.stl, face-back.dxf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]
2026-07-11 update enclosure
    [enclosure.scad, enclosure.stl, face-back.dxf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]
2026-07-18 add schematics
